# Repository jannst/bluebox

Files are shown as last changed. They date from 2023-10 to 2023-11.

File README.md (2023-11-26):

# BlueBox
The Bluebox Project aims to develop a board that incorporates a Bluetooth audio receiver and a power amplifier, designed to upgrade passive speakers into active Bluetooth speakers. The selection of Through-Hole Technology (THT) parts ensures that this project can be easily assembled in workshops without the need for sophisticated tools. The project utilizes the BM83 module from Microchip as the Bluetooth receiver.

## Prototype I (2023)
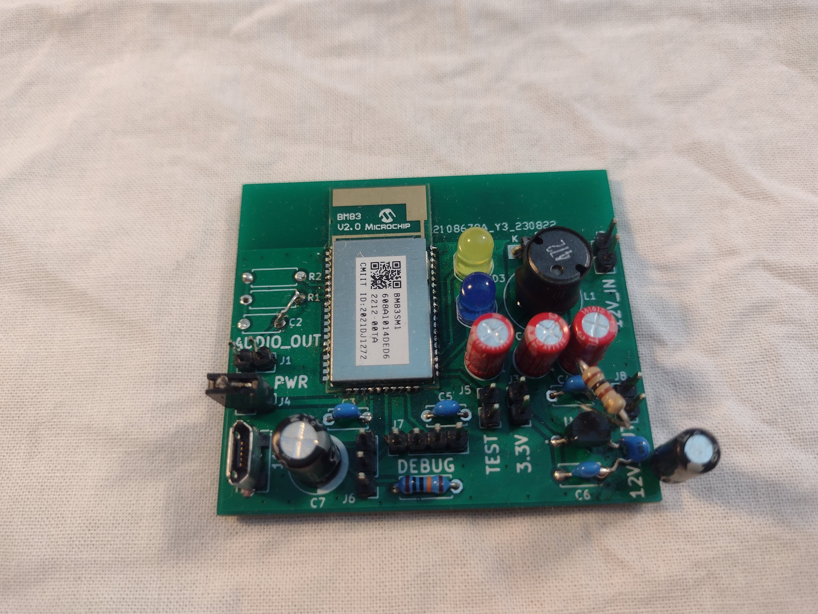
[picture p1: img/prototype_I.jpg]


The first prototype utilized an external audio board with a Texas Instruments TPA3116D amplifier. Unfortunately, a significant amount of digital switching noise from the BM83 module is amplified by the amplifier.

## Prototype II (WIP)
The second prototype will utilize a Texas Instruments TAS5828M amplifier. The amplifier chip will be integrated into the custom PCB. The advantage of the TAS5828M lies in its digital input, which is expected to prevent the amplification of switching noise.

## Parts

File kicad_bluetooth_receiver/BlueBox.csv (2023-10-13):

Source: | /home/metro/git/BlueBox/kicad_bluetooth_receiver/BlueBox.kicad_sch
Date: | Di 22 Aug 2023 10:26:44 CEST
Tool: | Eeschema 6.0.7-f9a2dced07~116~ubuntu20.04.1
Generator: | /usr/share/kicad/plugins/bom_csv_grouped_by_value_with_fp.py
Component Count: | 27
Ref | Qnty | Value | Cmp name | Footprint | Description | Vendor
11, | 1 | USB3145-30-1-A | USB3145-30-1-A | USB3145-30-1-A:USB3145301A | GCT (GLOBAL CONNECTOR TECHNOLOGY) - USB3145-30-1-A - MICRO USB, 2.0 TYPE B, RECEPTACLE, TH
C1, | 1 | 22u | C_Polarized | Capacitor_THT:CP_Radial_D5.0mm_P2.00mm | Polarized capacitor
C2, C4, | 2 | 1u | C | Capacitor_THT:C_Disc_D5.0mm_W2.5mm_P5.00mm | Unpolarized capacitor
C3, C5, | 2 | 0.1u | C | Capacitor_THT:C_Disc_D5.0mm_W2.5mm_P5.00mm | Unpolarized capacitor
C6, | 1 | 2.2u | C | Capacitor_THT:C_Disc_D5.0mm_W2.5mm_P5.00mm | Unpolarized capacitor
C7, | 1 | 100u | C_Polarized | Capacitor_THT:CP_Radial_D7.5mm_P2.50mm | Polarized capacitor
C8, C9, | 2 | 10u | C_Polarized | Capacitor_THT:CP_Radial_D5.0mm_P2.00mm | Polarized capacitor
D1, | 1 | D_Schottky | D_Schottky | Diode_THT:D_DO-41_SOD81_P7.62mm_Horizontal | Schottky diode
D2, D3, | 2 | LED | LED | LED_THT:LED_D5.0mm | Light emitting diode
J1, J2, J3, J4, J5, J8, | 6 | Conn_01x02_Male | Conn_01x02_Male | Connector_PinHeader_2.54mm:PinHeader_1x02_P2.54mm_Vertical | Generic connector, single row, 01x02, script generated (kicad-library-utils/schlib/autogen/connector/)
J6, | 1 | Conn_01x03_Male | Conn_01x03_Male | Connector_PinHeader_2.54mm:PinHeader_1x03_P2.54mm_Vertical | Generic connector, single row, 01x03, script generated (kicad-library-utils/schlib/autogen/connector/)
J7, | 1 | Conn_01x04_Male | Conn_01x04_Male | Connector_PinHeader_2.54mm:PinHeader_1x04_P2.54mm_Vertical | Generic connector, single row, 01x04, script generated (kicad-library-utils/schlib/autogen/connector/)
L1, | 1 | 4.7u | L | Inductor_THT:L_Radial_D10.5mm_P5.00mm_Abacron_AISR-01 | Inductor
R1, R2, | 2 | 1k | R | Resistor_THT:R_Axial_DIN0207_L6.3mm_D2.5mm_P7.62mm_Horizontal | Resistor
R3, | 1 | 100k | R | Resistor_THT:R_Axial_DIN0207_L6.3mm_D2.5mm_P7.62mm_Horizontal | Resistor
U1, | 1 | AP7381-33V-A | AP7381-33V-A | AP7381-33V-A:AP738133VA | LDO Voltage Regulators LDO CMOS LowCurr
U2, | 1 | BM83SM1-00TA | BM83SM1-00TA | BM83:BM83SM100TA | Bluetooth Modules (802.15.1) Bluetooth Audio Class 1 Transceiver Module with A2DP Source

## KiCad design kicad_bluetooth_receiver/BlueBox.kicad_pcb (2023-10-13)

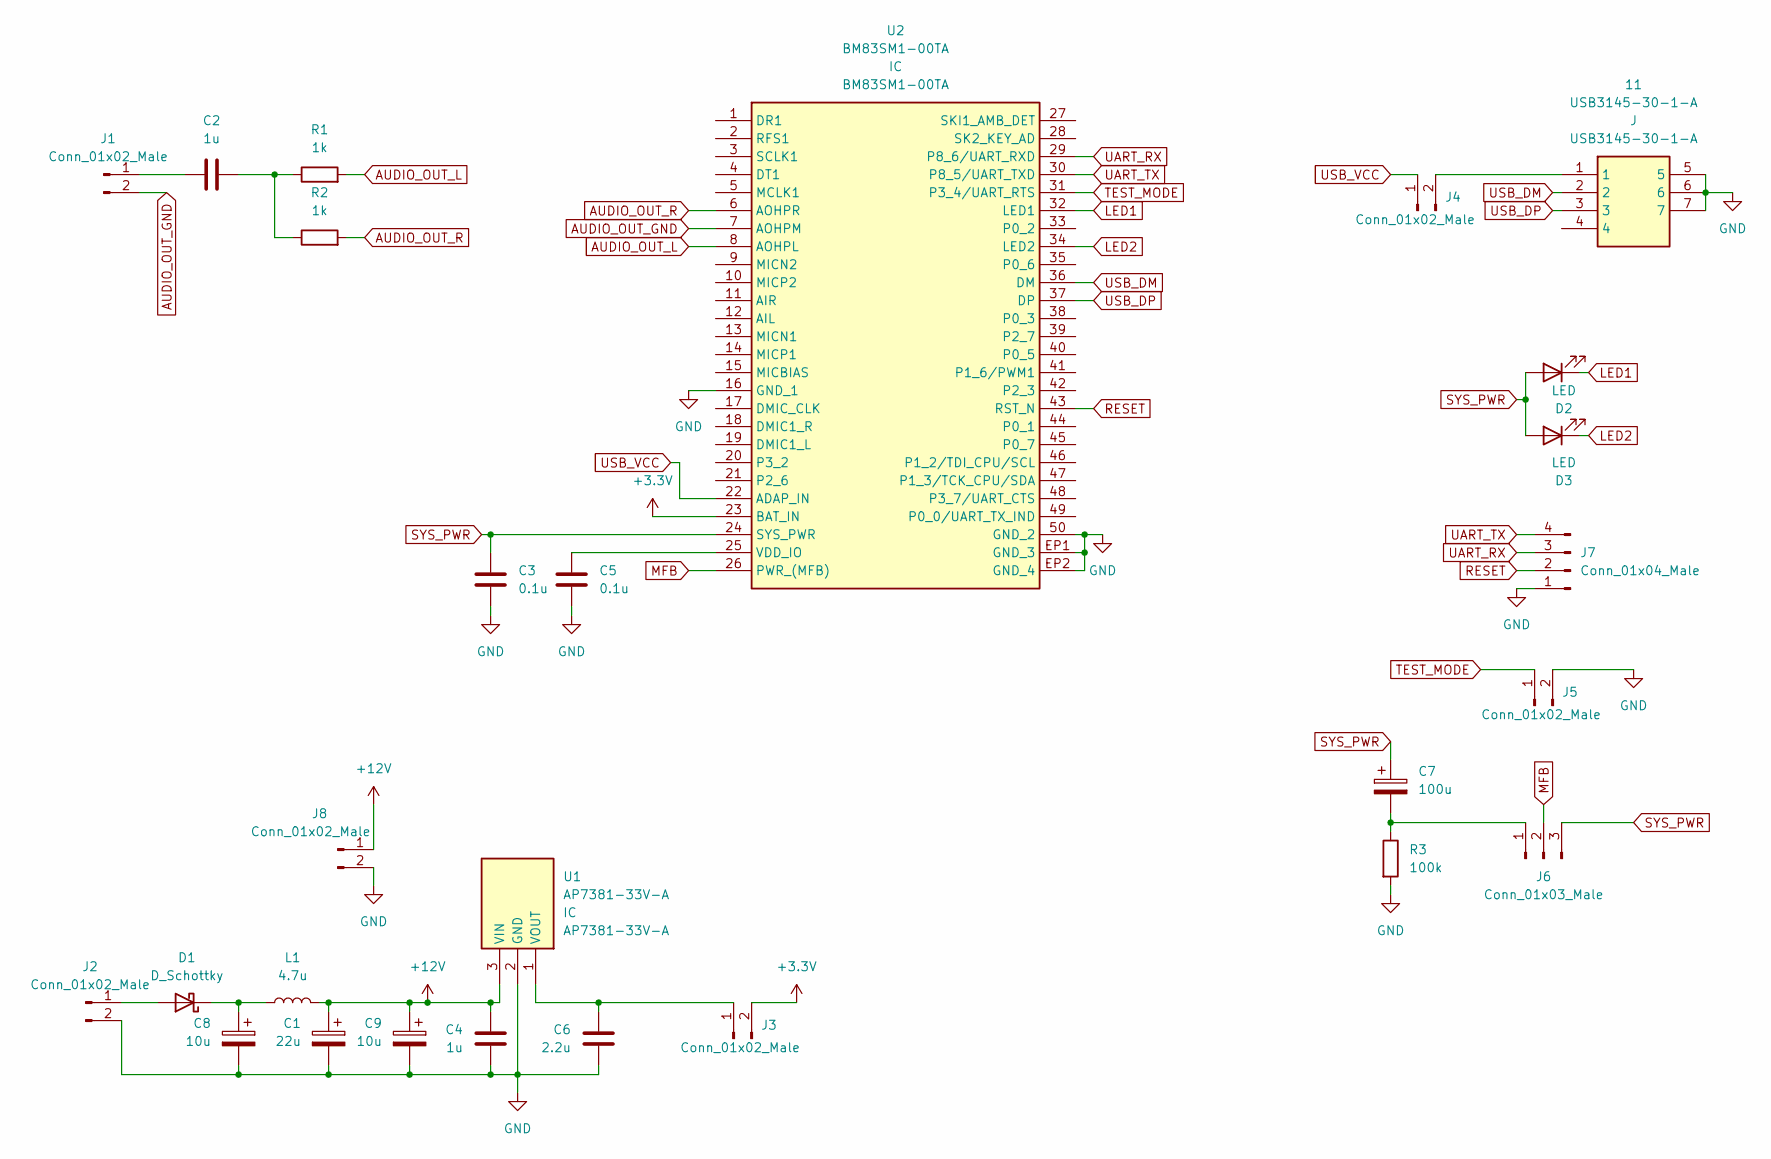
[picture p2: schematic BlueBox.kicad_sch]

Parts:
11: USB3145-30-1-A; USB3145301A; Mouser Part Number 640-USB3145-30-1-A
C1: 22u; CP_Radial_D5.0mm_P2.00mm
C2, C4: 1u; C_Disc_D5.0mm_W2.5mm_P5.00mm
C3, C5: 0.1u; C_Disc_D5.0mm_W2.5mm_P5.00mm
C6: 2.2u; C_Disc_D5.0mm_W2.5mm_P5.00mm
C7: 100u; CP_Radial_D7.5mm_P2.50mm
C8, C9: 10u; CP_Radial_D5.0mm_P2.00mm
D1: D_Schottky; D_DO-41_SOD81_P7.62mm_Horizontal
D2, D3: LED; LED_D5.0mm
J1, J2, J3, J4, J5, J8: Conn_01x02_Male; PinHeader_1x02_P2.54mm_Vertical
J6: Conn_01x03_Male; PinHeader_1x03_P2.54mm_Vertical
J7: Conn_01x04_Male; PinHeader_1x04_P2.54mm_Vertical
L1: 4.7u; L_Radial_D10.5mm_P5.00mm_Abacron_AISR-01
R1, R2: 1k; R_Axial_DIN0207_L6.3mm_D2.5mm_P7.62mm_Horizontal
R3: 100k; R_Axial_DIN0207_L6.3mm_D2.5mm_P7.62mm_Horizontal
U1: AP7381-33V-A; AP738133VA; Mouser Part Number 621-AP7381-33V-A
U2: BM83SM1-00TA; BM83SM100TA; Mouser Part Number 579-BM83SM1-00TA

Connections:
+3.3V: J3.2, U2.23 (BAT_IN)
+12V: C1.1, C4.2, C9.1, J8.1, L1.2, U1.3 (VIN)
AUDIO_OUT_GND: J1.2, U2.7 (AOHPM)
AUDIO_OUT_L: R1.2, U2.8 (AOHPL)
AUDIO_OUT_R: R2.2, U2.6 (AOHPR)
GND: 11.5, 11.6, 11.7, C1.2, C3.2, C4.1, C5.2, C6.1, C8.2, C9.2, J2.2, J5.2, J7.1, J8.2, R3.2, U1.2 (GND), U2.16 (GND_1), U2.50 (GND_2), U2.EP1 (GND_3), U2.EP2 (GND_4)
LED1: D2.1 (K), U2.32 (LED1)
LED2: D3.1 (K), U2.34 (LED2)
MFB: J6.2, U2.26 (PWR_(MFB))
unnamed: C5.1, U2.25 (VDD_IO)
unnamed: C6.2, J3.1, U1.1 (VOUT)
unnamed: C7.2, J6.1, R3.1
unnamed: C8.1, D1.1 (K), L1.1
unnamed: D1.2 (A), J2.1
unnamed: C2.2, J1.1
unnamed: 11.1, J4.2
unnamed: C2.1, R1.1, R2.1
RESET: J7.2, U2.43 (RST_N)
SYS_PWR: C3.1, C7.1, D2.2 (A), D3.2 (A), J6.3, U2.24 (SYS_PWR)
TEST_MODE: J5.1, U2.31 (P3_4/UART_RTS)
UART_RX: J7.3, U2.29 (P8_6/UART_RXD)
UART_TX: J7.4, U2.30 (P8_5/UART_TXD)
USB_DM: 11.2, U2.36 (DM)
USB_DP: 11.3, U2.37 (DP)
USB_VCC: J4.1, U2.22 (ADAP_IN)

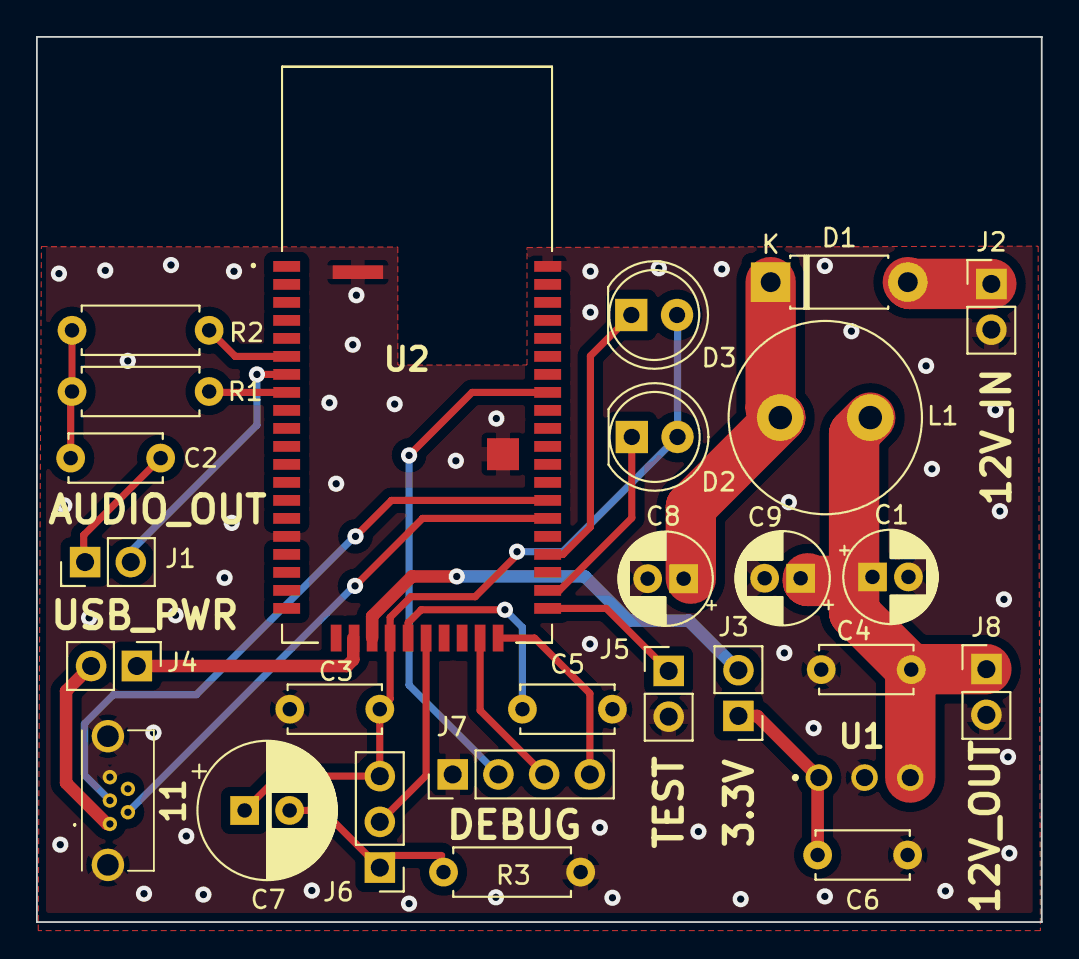
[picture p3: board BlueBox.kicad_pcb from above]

Board: 2 copper layers, 55.8 x 49.2 mm, 27 parts (0 on the bottom side), 25 nets.
